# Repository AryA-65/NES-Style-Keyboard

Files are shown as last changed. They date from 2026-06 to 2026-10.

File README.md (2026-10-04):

# NES-Style-Keyboard
- - - -
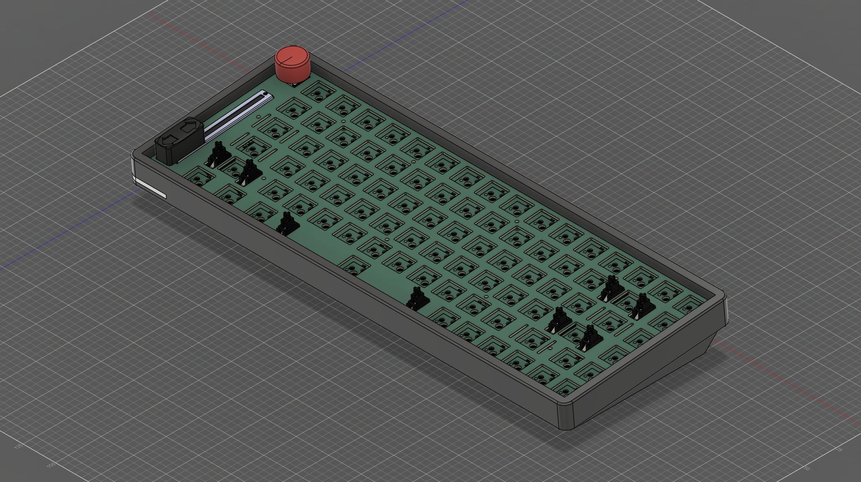
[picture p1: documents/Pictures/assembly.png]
Assembly


## Notice
- - - -
> [!IMPORTANT]  
> It is always advised that you review the files before ordering, as there may be small issues with the current revision.

## Description
- - - -
A friend of mine wanted to buy a keyboard. I convinced him to let me build him one. I decided to build him a custom 75% keyboard, with some extra features based on his preferences, and styled the color scheme to the popular NES. The whole keyboard, including the case, the main PCB, the switch plate and some of the caps, are custom designed by me.

## Gallery

## Features
- - - -
* Sliding Potentiometer
  * One of my friend's requests was to cater the keyboard more towards CAD design. The only right solution, in my opinion, is a sliding potentiometer for zoom control in apps like Fusion. To zoom using the slider, hold CTRL and move the slider up or down. To scroll horizontally, hold SHIFT and move the slider up or down.
* Rotary Encoder
  * The rotary encoder serves as playback control (play/pause/previous/skip), but also as volume control. If volume control is already mapped by the potentiometer, the encoder can serve to switch audio channels controlled by the potentiometer (ex: switching from the music media channel to the system audio channel)
* Addressable RGB LEDs
  * A total of 6 WS2812b leds are included on the left hand side of the keyboard, right next to the sliding potentiometer. They indicate volume level (if controlled by the potentiometer) and/or caps lock.
* Repairable Design
  * The power supplied to the main PCB comes from a small daughterboard at the back, middle of the case. This daughterboard consists of a 3V3 LDO as well as a fuse. The two PCBs are connected through a standard 15cm (0.5ft) USB-C cable, allowing for easy replacement by the user.
* Unibody Body Case
  * The case for the keyboard is as a unibody case. It is built to offer comfort, whilst keeping a thocky sound (it does sound awesome).
* Hot Swappable Keyswitches
  * Does this need to be explain at this point?

## Default keymaps
```
# Base Layer
[_BASE] = LAYOUT(
        KC_ESC, KC_F1, KC_F2, KC_F3, KC_F4, KC_F5, KC_F6, KC_F7, KC_F8, KC_F9, KC_F10, KC_F11, KC_F12, KC_HOME, KC_END, KC_PAUSE,
        KC_GRV, KC_1, KC_2, KC_3, KC_4, KC_5, KC_6, KC_7, KC_8, KC_9, KC_0, KC_MINS, KC_EQL,                    KC_BSPC, KC_INS,
        KC_TAB,     KC_Q, KC_W, KC_E, KC_R, KC_T, KC_Y, KC_U, KC_I, KC_O, KC_P, KC_LBRC, KC_RBRC,               KC_BSLS, KC_DEL,
        KC_CAPS,        KC_A, KC_S, KC_D, KC_F, KC_G, KC_H, KC_J, KC_K, KC_L, KC_SCLN, KC_QUOT,                 KC_ENT, KC_PGUP,
        KC_LSFT,            KC_Z, KC_X, KC_C, KC_V, KC_B, KC_N, KC_M, KC_COMM, KC_DOT, KC_SLSH, KC_RSFT,        KC_UP, KC_PGDN,
        KC_LCTL,    KC_LGUI,    KC_LALT,            KC_SPC,                   KC_RALT, MO(_FL), KC_RCTL, KC_LEFT, KC_DOWN, KC_RIGHT
    )

#Fn Layer
[_FL] = LAYOUT(
        _______, KC_PWR, KC_F2, KC_BRIU, KC_BRID, KC_F5, KC_MSEL, KC_F7, KC_F8, KC_F9, KC_F10, KC_F11, KC_F12, _______, _______, KC_SLEP,
        _______, _______, _______, _______, _______, _______, _______, _______, _______, _______, _______, UG_SPDD, UG_SPDU,              _______, UG_NEXT,
        _______, _______, _______, _______, _______, _______, _______, _______, _______, _______, _______, _______, _______, _______, UG_PREV,
        _______, _______, _______, _______, _______, _______, _______, _______, _______, _______, _______, _______,     _______, UG_SATU,
        _______, _______, _______, _______, _______, _______, _______, _______, _______, _______, _______, _______,     UG_VALU, UG_SATD,
        _______,    _______,    _______,            _______,                    _______, _______, _______, UG_HUED, UG_VALD, UG_HUEU
    )
```

## Parts List
- - - -
|Part|*Price|*Shipping|Link|
|----|---|---|----|
|Keycaps|$34.18|NaN|[XDA Retro NES Keycaps](https://www.aliexpress.com/item/1005007393936770.html?spm=a2g0o.order_list.order_list_main.25.587f1802SPZi3h)|
|Keyswitches (90pcs)|$32.18|NaN|[MMD Cream Switches (45G)](https://www.aliexpress.com/item/1005007083480212.html?spm=a2g0o.order_list.order_list_main.35.587f1802SPZi3h)|
|Hotswap Sockets (110ps)|$12.21|NaN|[110pcs Kailh Hot-swappable Sockets](https://www.aliexpress.com/item/1005007232040760.html?spm=a2g0o.order_list.order_list_main.30.587f1802SPZi3h)|
|Diodes|$3.17|NaN|[100pcs 1N4148W](https://www.aliexpress.com/item/1005009660071572.html?spm=a2g0o.order_list.order_list_main.20.587f1802SPZi3h)|
|Stabilizers|$25.99|NaN|[Durock Screw in Stabilizers V3 (Black)](https://www.aliexpress.com/item/1005003682325989.html?spm=a2g0o.order_list.order_list_main.10.587f1802SPZi3h)|
|USB-C Cable|$12.64|NaN|[6 inch USB C to USB C Cable (3 Pack)](https://www.amazon.ca/dp/B0CLLRBZDB)|
|BOM|$34.96|$8.00|[BOMs](production_files)|
|Main PCB|$31.20|$43.78**|[Main PCB](production_files/gerbers_to_order_main)|
|Daughterboard|$3.00|$43.78**|[Daughterboard PCB](production_files/gerbers_to_order_secondary)|
|Switch Plate****|$0.00|NaN|[Plate PCB](production_files/gerbers_to_order_plate)|
|Case|$65.13|$43.78**|[Enclosure](production_files/3D_files/)|
|Misc.|$6.50***|$43.78**|[Misc. Parts](production_files/3D_files/)|

Total (excluding import fees): $298.66

*All prices are in CAD, check in your own currency before buying.
**Combined shipping for keyboard and daughterboard PCB, misc. items and enclosure.
***Includes encoder knob, slider handle, power led bar and status bar
****I decided to print the switchplate at home, since it was much cheaper per unit and overall compared to ordering it (price will be updated soon).

## Quickstart
- - - -
### 1) First flash
This step if for first flash, right after assembling your PCBs:
1) Download the UF2 prebuilt firmware in [firmware](firmware/).
2) Connect main board to daughterboard through USB-C intercable (**never connect a USB-C cable directly to the main PCB, it will damage the board**).
3) Press and hold EN button on keyboard.
4) Plug USB-C cable from computer to daughterboard, and let go of the EN button.
5) A USB device will appear in your file explorer, drag and drop UF2 file from your downloads folder into the USB device.
6) If the keyboard automatically resets, the flash was successful. Otherwise, try flashing again.

### 2) Reflash
Since the EN button is on the opposite side of the board and not accessible once the keyboard is assembled, I added a key combo that resets the board and enables flashing new firmware:
1) Press and release right CTRL, ESC, left CTRL and END button at the same time.
2) Drag and drop UF2 firmware from your computer onto the keyboard.
3) If the keyboard automatically resets, the flash was successful. Otherwise, try flashing again (step 1).

## Support
- - - -
Coming Soon

## Tools Used
- - - -
- [Kicad](https://www.kicad.org/)
- [Keyboard Layout Editor](https://www.keyboard-layout-editor.com/#/)
- [Autodesk Fusion](https://www.autodesk.com/products/fusion-360/overview)
- [QMK Firmawre](https://qmk.fm/)

## Legal Notice
- - - -
The software and hardware come as is. It is up to the user to review and make sure that they understand the scope of the project before attempting the project.
[GPL V2 License](LICENSE)

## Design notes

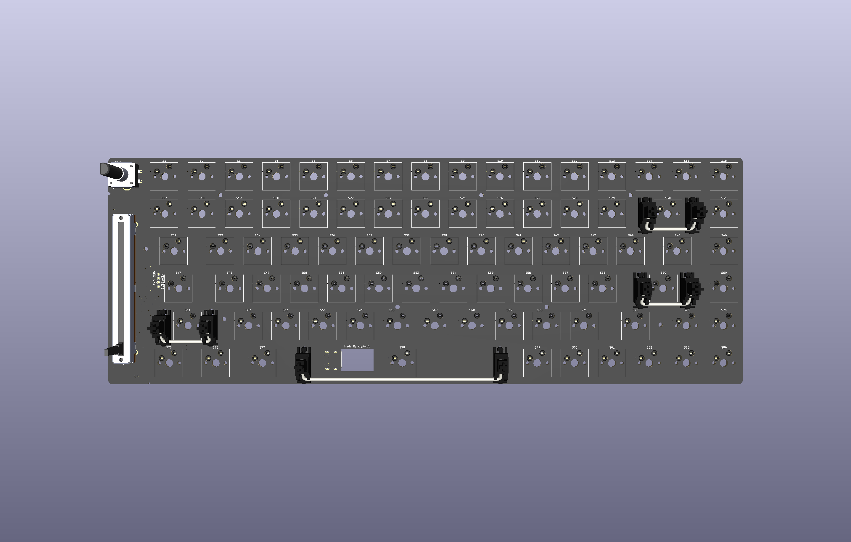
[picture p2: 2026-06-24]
documents/Pictures/main_pcb_picture_f.png

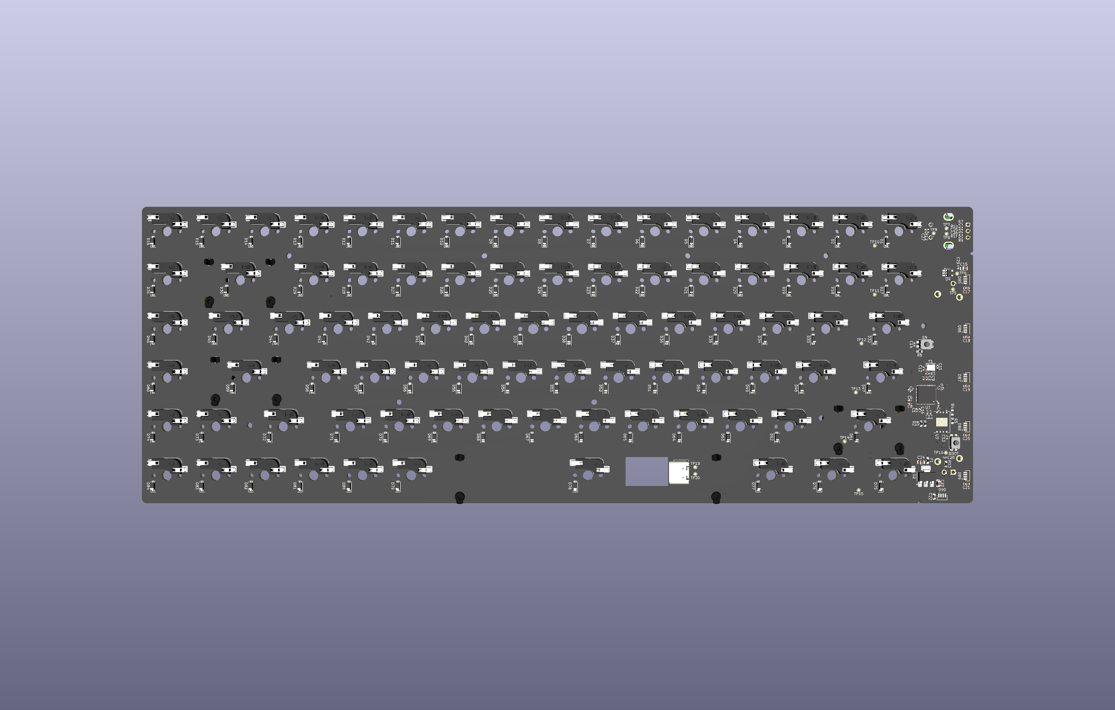
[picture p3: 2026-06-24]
documents/Pictures/main_pcb_picture_b.png

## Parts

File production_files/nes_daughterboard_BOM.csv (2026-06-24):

Reference | Qty | Value | Footprint | Datasheet | Digikey Link | Part Num.
C1,C2 | 2 | 10uF | Capacitor_SMD:C_0805_2012Metric |  | https://www.digikey.ca/en/products/detail/samsung-electro-mechanics/CL21A106KOQNNNE/3886754 | CL21A106KOQNNNE
D1,D2 | 2 | Red | LED_SMD:LED_0603_1608Metric_Pad1.05x0.95mm_HandSolder |  | https://www.digikey.ca/en/products/detail/liteon/LTST-C191KRKT/386837 | LTST-C191KRKT
F1 | 1 | 500mA | Fuse:Fuse_0603_1608Metric |  | https://www.digikey.ca/en/products/detail/panasonic-industry/ERB-RE0R50V/2796788 | ERB-RE0R50V
J1 | 1 | USB_C_Receptacle_USB2.0_16P | Connector_USB:USB_C_Receptacle_GCT_USB4085 | https://www.usb.org/sites/default/files/documents/usb_type-c.zip | https://www.digikey.ca/en/products/detail/gct/USB4085-GF-A/9859662 | USB4085-GF-A
J3 | 1 | USB_C_Receptacle_USB2.0_16P | Connector_USB:USB_C_Receptacle_GCT_USB4105-xx-A_16P_TopMnt_Horizontal | https://www.usb.org/sites/default/files/documents/usb_type-c.zip | https://www.digikey.ca/en/products/detail/gct/USB4105-GF-A/11198441 | USB4105-GF-A
R1,R2 | 2 | 5.11k | Resistor_SMD:R_0603_1608Metric_Pad0.98x0.95mm_HandSolder |  | https://www.digikey.ca/en/products/detail/yageo/RC0603FR-075K1L/727268 | RC0603FR-075K1L
R3 | 1 | 680 | Resistor_SMD:R_0603_1608Metric_Pad0.98x0.95mm_HandSolder |  | https://www.digikey.ca/en/products/detail/yageo/RC0603JR-07680RL/726819 | RC0603JR-07680RL
R4 | 1 | 470 | Resistor_SMD:R_0603_1608Metric_Pad0.98x0.95mm_HandSolder |  | https://www.digikey.ca/en/products/detail/te-connectivity-passive-product/CRGCQ0603F470R/8576286 | CRGCQ0603F470R
U1 | 1 | NCP1117-3.3_SOT223 | Package_TO_SOT_SMD:SOT-223-3_TabPin2 | http://www.onsemi.com/pub_link/Collateral/NCP1117-D.PDF | https://www.digikey.ca/en/products/detail/onsemi/NCP1117LPST33T3G/2194024 | NCP1117LPST33T3G
U2 | 1 | USBLC6-2P6 | Package_TO_SOT_SMD:SOT-666 | https://www.st.com/resource/en/datasheet/usblc6-2.pdf | https://www.digikey.ca/en/products/detail/stmicroelectronics/USBLC6-2P6/1007440 | USBLC6-2P6

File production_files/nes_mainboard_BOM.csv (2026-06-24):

Reference | Qty | Value | Footprint | Part Num. | Digikey Link
C1,C16 | 2 | 1uF | Capacitor_SMD:C_0402_1005Metric | CL05A105KP5NNNC | https://www.digikey.ca/en/products/detail/samsung-electro-mechanics/CL05A105KP5NNNC/3886734
C2,C3,C4,C5,C6,C7,C8,C9,C10,C13,C14,C25,C26,C27,C28,C29 | 16 | 0.1uF | Capacitor_SMD:C_0402_1005Metric | CL05B104KP5NNNC | https://www.digikey.ca/en/products/detail/samsung-electro-mechanics/CL05B104KP5NNNC/3886660
C11,C12 | 2 | 15pF | Capacitor_SMD:C_0402_1005Metric | 885012005026 | https://www.digikey.ca/en/products/detail/w%C3%BCrth-elektronik/885012005026/5453297
C15 | 1 | 10uF | Capacitor_SMD:C_0805_2012Metric | CL21A106KOQNNNE | https://www.digikey.ca/en/products/detail/samsung-electro-mechanics/CL21A106KOQNNNE/3886754
C17,C18,C19,C20,C21,C22 | 6 | 100nF | Capacitor_SMD:C_0603_1608Metric | CL10B104KO8NNNC | https://www.digikey.ca/en/products/detail/samsung-electro-mechanics/CL10B104KO8NNNC/3886663
D1,D2,D3,D4,D5,D6,D7,D8,D9,D10,D11,D12,D13,D14,D15,D16,D17,D18,D19,D20,D21,D22,D23,D24,D25,D26,D27,D28,D29,D30,D31,D32,D33,D34,D35,D36,D37,D38,D39,D40,D41,D42,D43,D44,D45,D46,D47,D48,D49,D50,D51,D52,D53,D54,D55,D56,D57,D58,D59,D60,D61,D62,D63,D64,D65,D66,D67,D68,D69,D70,D71,D72,D73,D74,D75,D76,D77,D78,D79,D80,D81,D82,D83,D84 | 84 | 1N4148W | Diode_SMD:D_SOD-123 | 1N4148W | https://www.digikey.ca/en/products/detail/smc-diode-solutions/1N4148W/6022450
D85,D86,D87,D88,D89,D90 | 6 | WS2812B | LED_WS2812B-4020:LED_WS2812B-4020 |  | https://www.aliexpress.com/item/1005006254176042.html
J1 | 1 | USB_C_Receptacle_USB2.0_16P | Connector_USB:USB_C_Receptacle_GCT_USB4105-xx-A_16P_TopMnt_Horizontal | USB4105-GF-A | https://www.digikey.ca/en/products/detail/gct/USB4105-GF-A/11198441
R1,R2 | 2 | 27.4 | Resistor_SMD:R_0603_1608Metric | RC0603FR-0727R4L | https://www.digikey.ca/en/products/detail/yageo/RC0603FR-0727R4L/727101
R3 | 1 | 1k | Resistor_SMD:R_0402_1005Metric | RC0402FR-071KL | https://www.digikey.ca/en/products/detail/yageo/RC0402FR-071KL/726513
R5 | 1 | 1k | Resistor_SMD:R_0603_1608Metric | RC0603FR-071KL | https://www.digikey.ca/en/products/detail/yageo/RC0603FR-071KL/726843
R7,R9,R10,R11,R12 | 5 | 10k | Resistor_SMD:R_0402_1005Metric | RMCF0402FT10K0 | https://www.digikey.ca/en/products/detail/stackpole-electronics-inc/RMCF0402FT10K0/1761433
R8 | 1 | 10k | Resistor_SMD:R_0603_1608Metric | RMCF0603FT10K0 | https://www.digikey.ca/en/products/detail/stackpole-electronics-inc/RMCF0603FT10K0/1761235
R13 | 1 | 100 | Resistor_SMD:R_0603_1608Metric | RC0603FR-07100RL | https://www.digikey.ca/en/products/detail/yageo/RC0603FR-07100RL/726888
RV1 | 1 | R_Potentiometer | PTA6043_2015DPB103:TRIM_PTA6043-2015DPB103 | PTA6043-2010CIB103 | https://www.digikey.ca/en/products/detail/bourns-inc/PTA6043-2010CIB103/3781224
S1,S2,S3,S4,S5,S6,S7,S8,S9,S10,S11,S12,S13,S14,S15,S16,S17,S18,S19,S20,S21,S22,S23,S24,S25,S26,S27,S28,S29,S31,S33,S34,S35,S36,S37,S38,S39,S40,S41,S42,S43,S44,S46,S48,S49,S50,S51,S52,S53,S54,S55,S56,S57,S58,S60,S62,S63,S64,S65,S66,S67,S68,S69,S70,S71,S73,S74,S79,S80,S81,S82,S83,S84 | 73 | Keyswitch | ScottoKeebs_Hotswap:Hotswap_MX_1.00u
S30 | 1 | Keyswitch | ScottoKeebs_Hotswap:Hotswap_MX_2.00u
S32,S45 | 2 | Keyswitch | ScottoKeebs_Hotswap:Hotswap_MX_1.50u
S47,S72 | 2 | Keyswitch | ScottoKeebs_Hotswap:Hotswap_MX_1.75u
S59,S61 | 2 | Keyswitch | ScottoKeebs_Hotswap:Hotswap_MX_2.25u
S75,S76,S77 | 3 | Keyswitch | ScottoKeebs_Hotswap:Hotswap_MX_1.25u
S78 | 1 | Keyswitch | ScottoKeebs_Hotswap:Hotswap_MX_6.25u
S85,S86,S87 | 3 | Keyswitch | PCM_Mounting_Keyboard_Stabilizer:Stabilizer_Cherry_MX_2.00u
S88 | 1 | Keyswitch | PCM_Mounting_Keyboard_Stabilizer:Stabilizer_Cherry_MX_6.25u
SW1,SW2 | 2 | SW_Push | Button_Switch_SMD:SW_SPST_EVQP2_MiddlePushTravel_H2.5mm | EVQ-P2402W | https://www.digikey.ca/en/products/detail/panasonic-industry/EVQ-P2402W/304152
SW3 | 1 | RotaryEncoder_Switch_MP | Rotary_Encoder:RotaryEncoder_Bourns_Vertical_PEC12R-3x17F-Sxxxx | PEC12R-4217F-S0024 | https://www.digikey.ca/en/products/detail/bourns-inc/PEC12R-4217F-S0024/4499654
TP1,TP2,TP3,TP4,TP5,TP6,TP7,TP8,TP9,TP10,TP11,TP12,TP13,TP14,TP15,TP16,TP19,TP20 | 18 | TestPoint | TestPoint:TestPoint_Pad_D1.0mm
U1 | 1 | RP2040 | Package_DFN_QFN:QFN-56-1EP_7x7mm_P0.4mm_EP3.2x3.2mm_ThermalVias | SC0914(13) | https://www.digikey.ca/en/products/detail/raspberry-pi/SC0914-13/14306010
U3 | 1 | W25Q128JVE | Package_SON:WSON-8-1EP_8x6mm_P1.27mm_EP3.4x4.3mm | W25Q128JVEIQ | https://www.digikey.ca/en/products/detail/winbond-electronics/W25Q128JVEIQ/6819667
U4 | 1 | 74AHCT1G125 | Package_TO_SOT_SMD:SOT-23-5_HandSoldering | SN74AHCT1G125DBVR | https://www.digikey.ca/en/products/detail/texas-instruments/SN74AHCT1G125DBVR/376028
Y1 | 1 | Crystal_GND24 | Crystal:Crystal_SMD_3225-4Pin_3.2x2.5mm | ABM8-272-T3 | https://www.digikey.ca/en/products/detail/abracon-llc/ABM8-272-T3/22472366

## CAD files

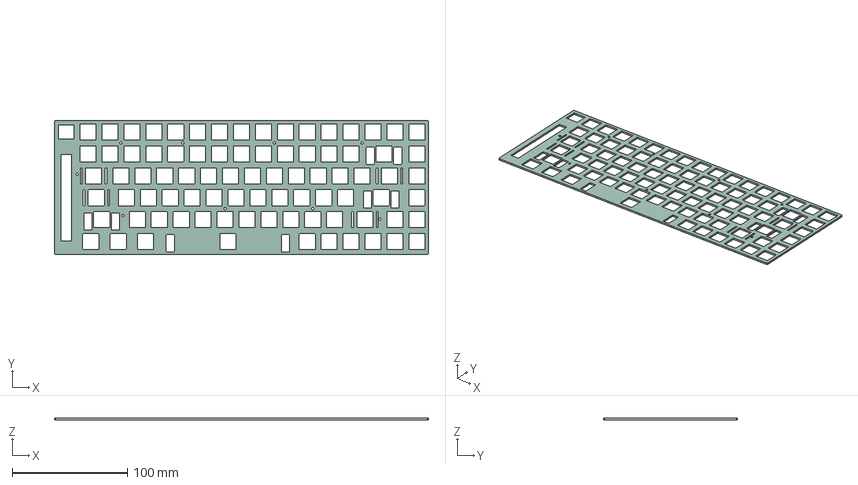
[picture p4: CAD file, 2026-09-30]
nes_switchplate/nes_switchplate.step
325.0 x 116.5 x 1.64 mm
nes_switchplate-unsaved-export-xho6La_silkscreen
nes_switchplate-unsaved-export-xho6La_soldermask x 2
nes_switchplate-unsaved-export-xho6La_PCB

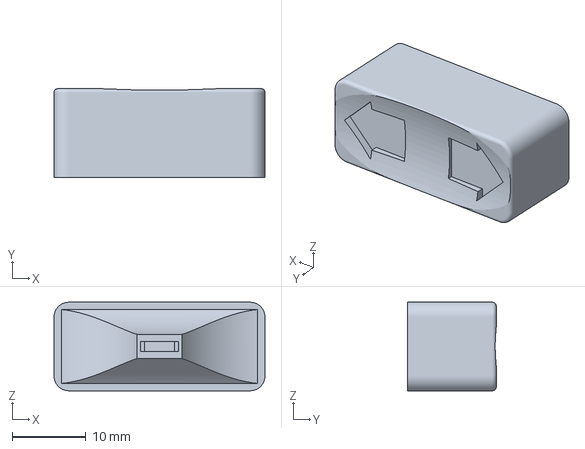
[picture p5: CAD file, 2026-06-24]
production_files/3D_files/Slider Handle.3mf
28.6 x 12.0 x 12.0 mm

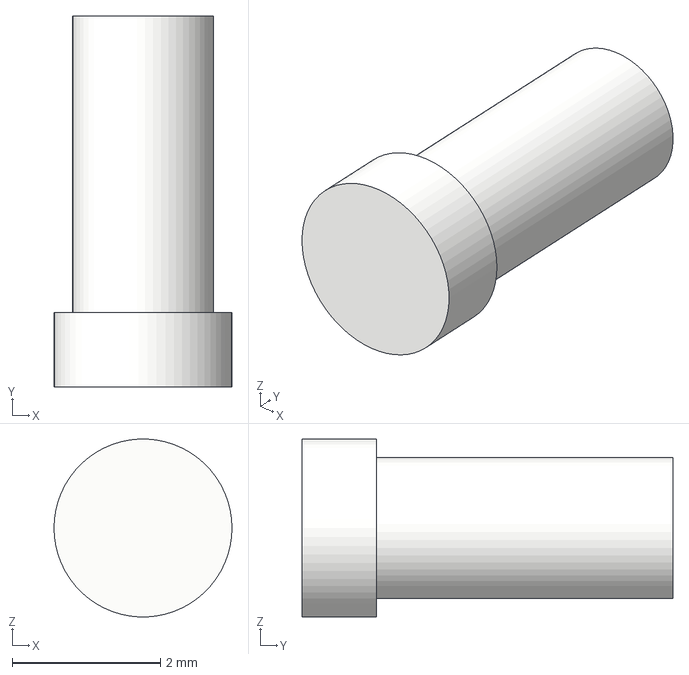
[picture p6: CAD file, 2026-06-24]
production_files/3D_files/pin.3mf
2.40 x 5.00 x 2.40 mm

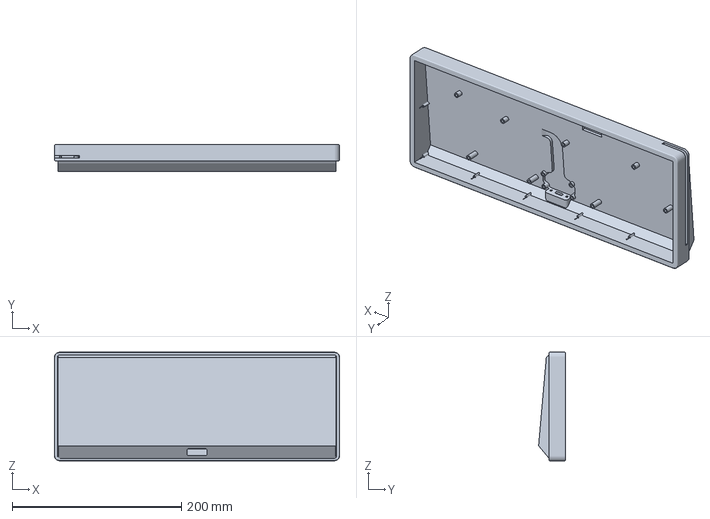
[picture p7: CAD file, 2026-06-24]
production_files/3D_files/Case (V2).3mf
337.0 x 31.8 x 128.5 mm

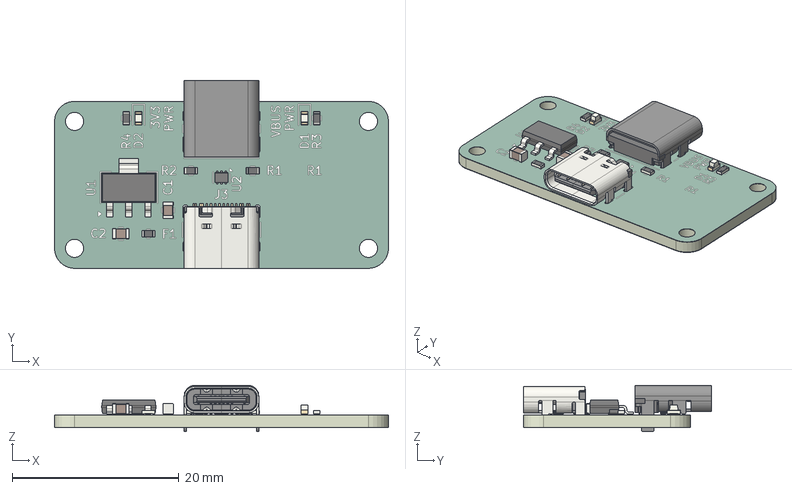
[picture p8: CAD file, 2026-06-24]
production_files/3D_files/daughterboard.step
40.0 x 22.5 x 5.56 mm
R_0603_1608Metric x 4
C_0805_2012Metric x 2
SOT_666
LED_0603_1608Metric x 2
USB_C_Receptacle_GCT_USB4085
USB_C_Receptacle_16P_TopMnt_Horizontal_GCT_USB4105-xx-A
SOT-223
Fuse_0603_1608Metric
nes_keyboard_daughterboard_silkscreen
nes_keyboard_daughterboard_soldermask x 2
nes_keyboard_daughterboard_PCB

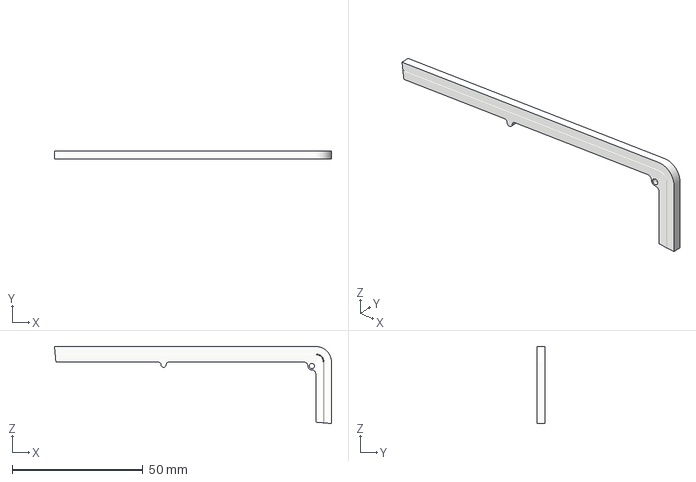
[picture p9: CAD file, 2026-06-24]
production_files/3D_files/Status Bar (V2).3mf
106.0 x 3.05 x 29.5 mm

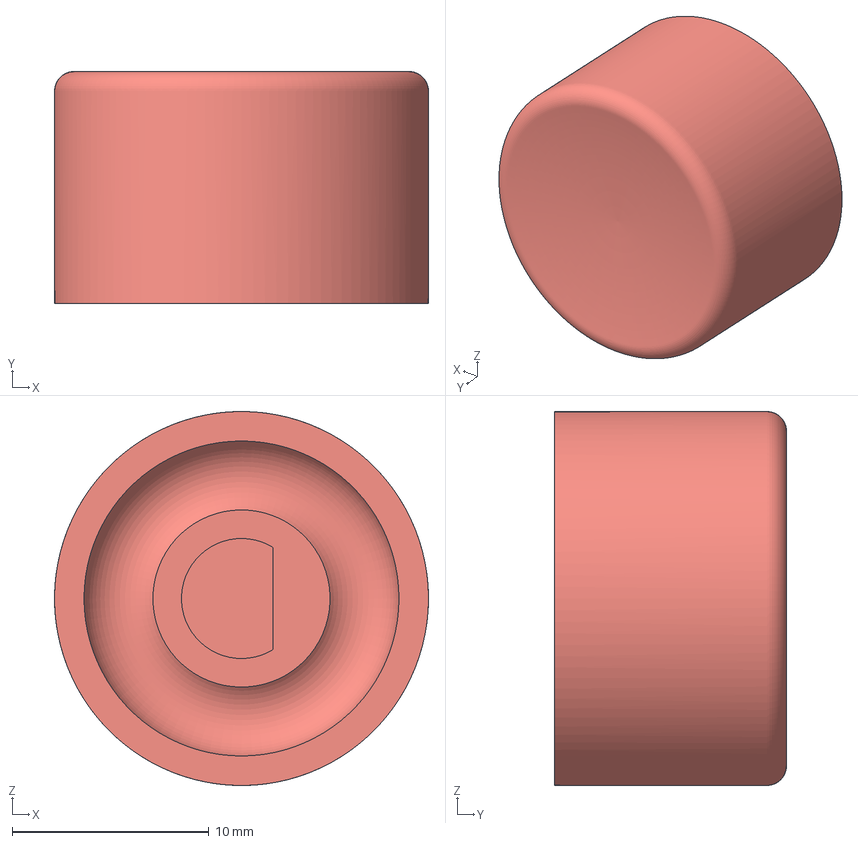
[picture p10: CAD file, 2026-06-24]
production_files/3D_files/Knob.3mf
19.0 x 11.8 x 19.0 mm

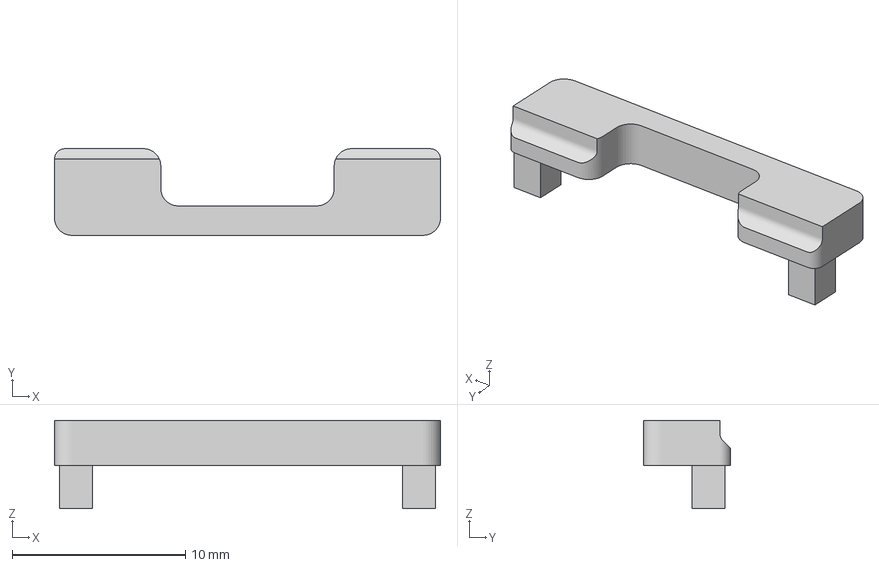
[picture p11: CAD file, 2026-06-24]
production_files/3D_files/PWR Status (V2).3mf
22.3 x 5.00 x 5.10 mm

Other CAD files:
production_files/3D_files/switchplate.step

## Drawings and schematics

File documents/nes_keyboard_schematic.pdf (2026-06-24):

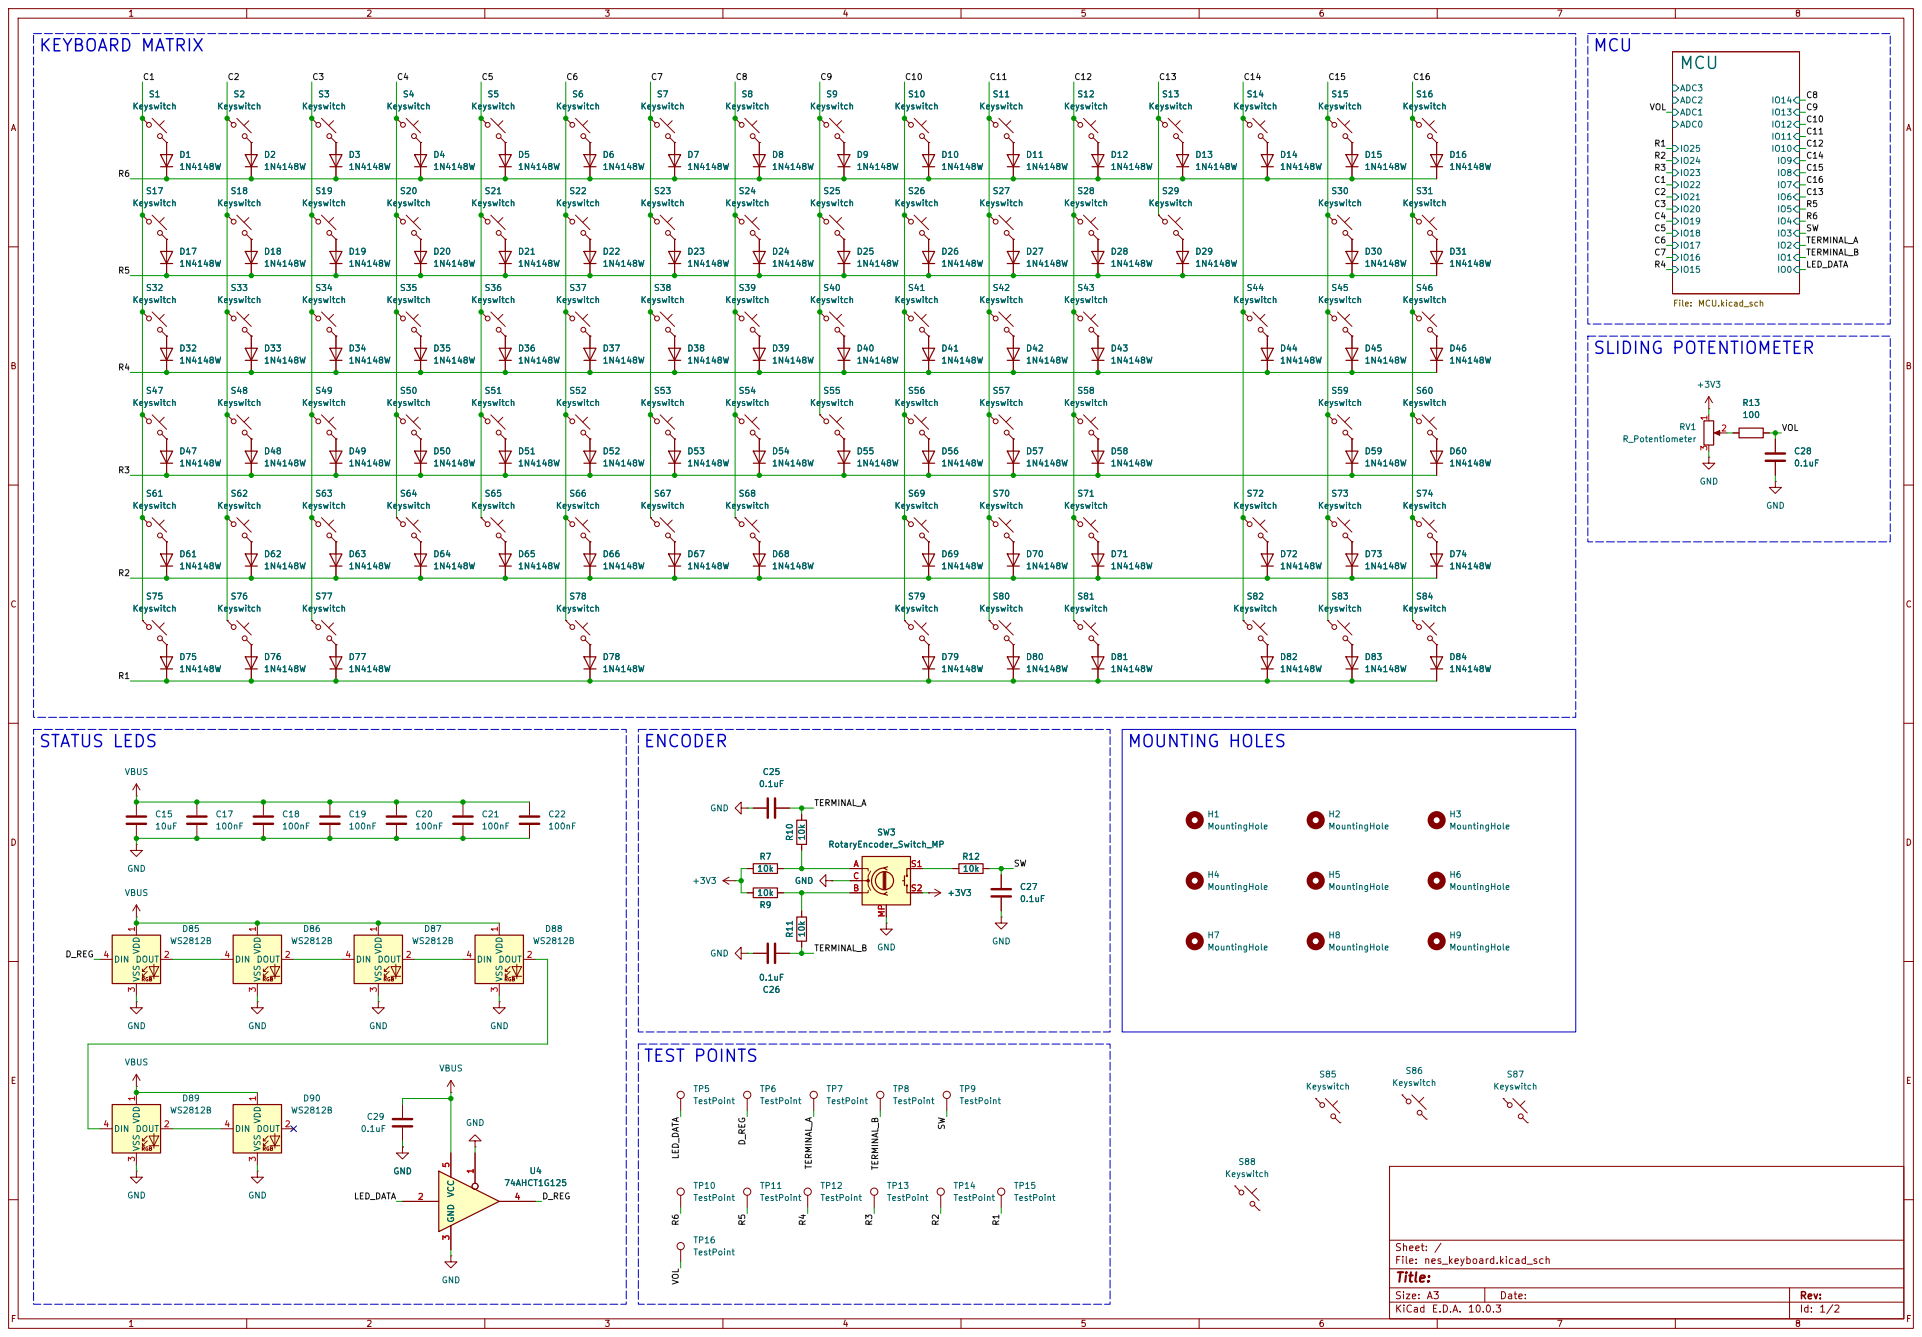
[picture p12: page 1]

S28 Keyswitch S43 Keyswitch S42 Keyswitch S27 Keyswitch D27

Size: A3 | Rev: | F Date:
KiCad E.D.A. 10.0.3 | Id: 1/2

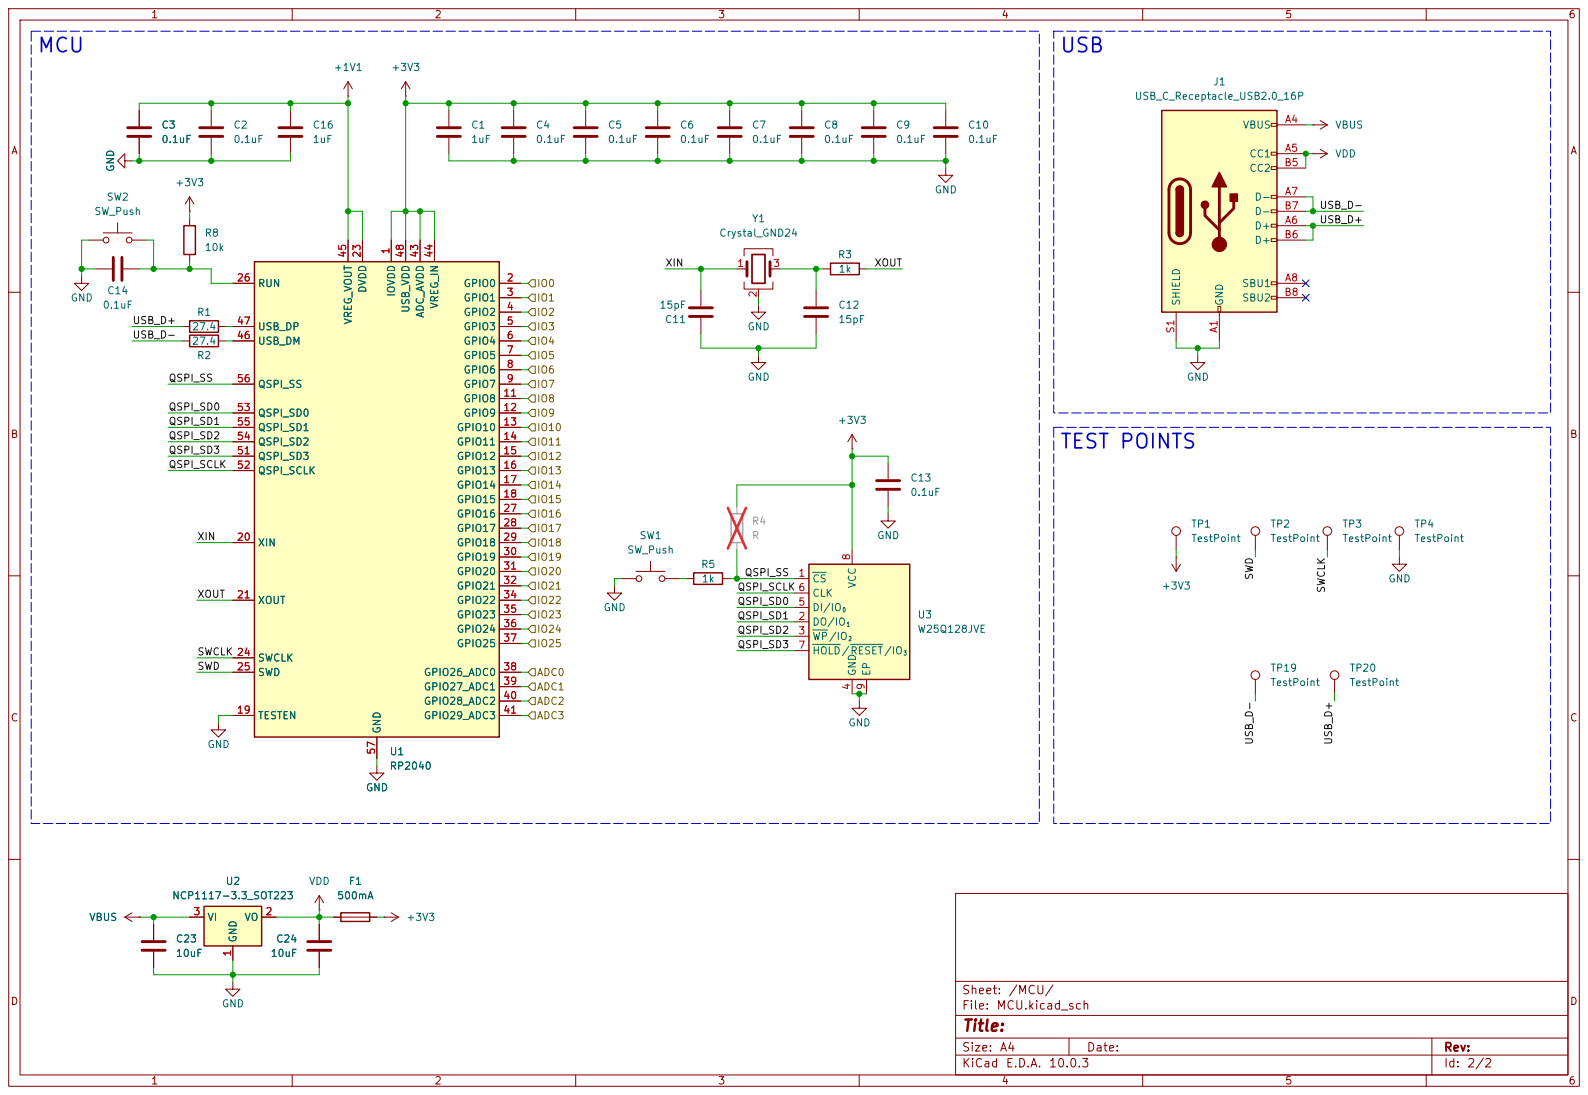
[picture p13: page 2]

4 DI/IO0 5 CLK 6 HOLD/RESET/IO3 7 VCC

Size: A4 | Rev:
KiCad E.D.A. 10.0.3 | Id: 2/2

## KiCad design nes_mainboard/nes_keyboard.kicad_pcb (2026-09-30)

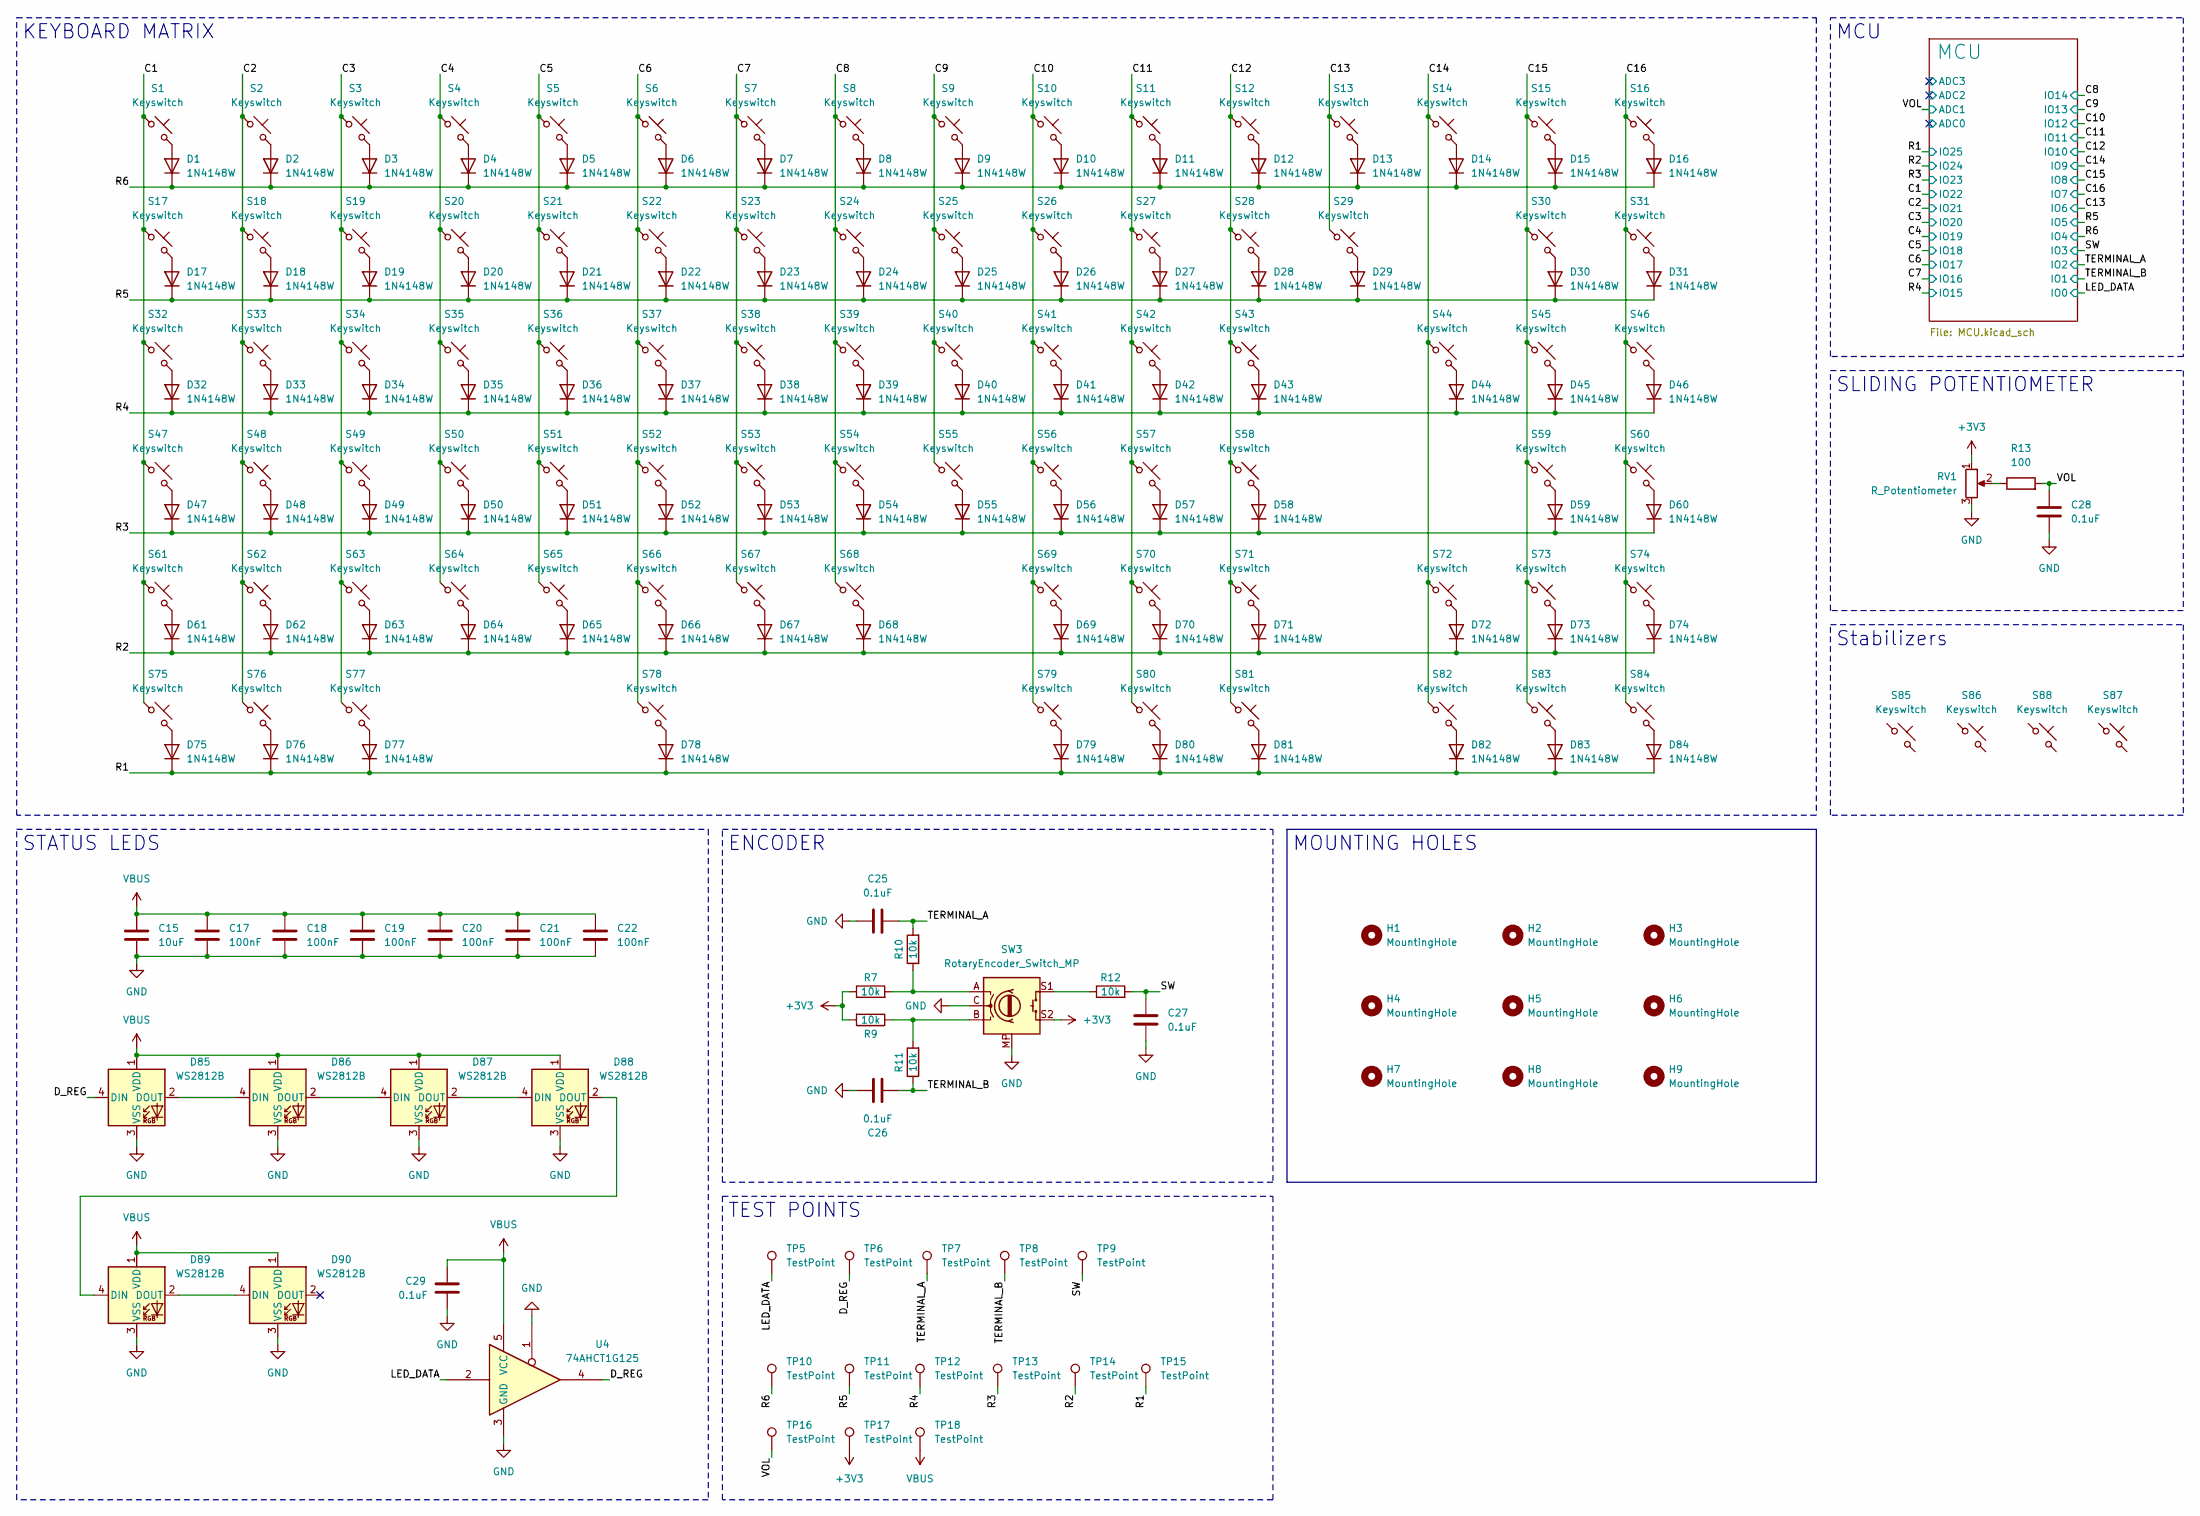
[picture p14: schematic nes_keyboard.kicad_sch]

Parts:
C15: 10uF; C_0805_2012Metric; Part Num. CL21A106KOQNNNE
C17, C18, C19, C20, C21, C22: 100nF; C_0603_1608Metric; Part Num. CL10B104KO8NNNC
C25, C26, C27, C28, C29: 0.1uF; C_0402_1005Metric; Part Num. CL05B104KP5NNNC
D1, D2, D3, D4, D5, D6, D7, D8, D9, D10, D11, D12, D13, D14, D15, D16, D17, D18, D19, D20, D21, D22, D23, D24, D25, D26, D27, D28, D29, D30, D31, D32, D33, D34, D35, D36, D37, D38, D39, D40, D41, D42, D43, D44, D45, D46, D47, D48, D49, D50, D51, D52, D53, D54, D55, D56, D57, D58, D59, D60, D61, D62, D63, D64, D65, D66, D67, D68, D69, D70, D71, D72, D73, D74, D75, D76, D77, D78, D79, D80, D81, D82, D83, D84: 1N4148W; D_SOD-123; Part Num. 1N4148W
D85, D86, D87, D88, D89, D90: WS2812B; LED_WS2812B-4020
H1, H2, H3, H4, H5, H6, H7, H8, H9: MountingHole; MountingHole_2.2mm_M2_Pad
R7, R9, R10, R11, R12: 10k; R_0402_1005Metric; Part Num. RMCF0402FT10K0
R13: 100; R_0603_1608Metric; Part Num. RC0603FR-07100RL
RV1: R_Potentiometer; TRIM_PTA6043-2015DPB103; Part Num. PTA6043-2010CIB103
S1, S2, S3, S4, S5, S6, S7, S8, S9, S10, S11, S12, S13, S14, S15, S16, S17, S18, S19, S20, S21, S22, S23, S24, S25, S26, S27, S28, S29, S31, S33, S34, S35, S36, S37, S38, S39, S40, S41, S42, S43, S44, S46, S48, S49, S50, S51, S52, S53, S54, S55, S56, S57, S58, S60, S62, S63, S64, S65, S66, S67, S68, S69, S70, S71, S73, S74, S79, S80, S81, S82, S83, S84: Keyswitch; Hotswap_MX_1.00u
S30: Keyswitch; Hotswap_MX_2.00u
S32, S45: Keyswitch; Hotswap_MX_1.50u
S47, S72: Keyswitch; Hotswap_MX_1.75u
S59, S61: Keyswitch; Hotswap_MX_2.25u
S75, S76, S77: Keyswitch; Hotswap_MX_1.25u
S78: Keyswitch; Hotswap_MX_6.25u
S85, S86, S87: Keyswitch; Stabilizer_Cherry_MX_2.00u
S88: Keyswitch; Stabilizer_Cherry_MX_6.25u
SW3: RotaryEncoder_Switch_MP; RotaryEncoder_Bourns_Vertical_PEC12R-3x17F-Sxxxx; Part Num. PEC12R-4217F-S0024
TP5, TP6, TP7, TP8, TP9, TP10, TP11, TP12, TP13, TP14, TP15, TP16, TP17, TP18: TestPoint; TestPoint_Pad_D1.0mm
U4: 74AHCT1G125; SOT-23-5_HandSoldering; Part Num. SN74AHCT1G125DBVR

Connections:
+3V3: R7.1, R9.2, RV1.1, SW3.S2, TP17.1 (1_1); also elsewhere on the board
/C1: S1.1, S17.1, S32.1, S47.1, S61.1, S75.1; also elsewhere on the board
/C2: S2.1, S18.1, S33.1, S48.1, S62.1, S76.1; also elsewhere on the board
/C3: S3.1, S19.1, S34.1, S49.1, S63.1, S77.1; also elsewhere on the board
/C4: S4.1, S20.1, S35.1, S50.1, S64.1; also elsewhere on the board
/C5: S5.1, S21.1, S36.1, S51.1, S65.1; also elsewhere on the board
/C6: S6.1, S22.1, S37.1, S52.1, S66.1, S78.1; also elsewhere on the board
/C7: S7.1, S23.1, S38.1, S53.1, S67.1; also elsewhere on the board
/C8: S8.1, S24.1, S39.1, S54.1, S68.1; also elsewhere on the board
/C9: S9.1, S25.1, S40.1, S55.1; also elsewhere on the board
/C10: S10.1, S26.1, S41.1, S56.1, S69.1, S79.1; also elsewhere on the board
/C11: S11.1, S27.1, S42.1, S57.1, S70.1, S80.1; also elsewhere on the board
/C12: S12.1, S28.1, S43.1, S58.1, S71.1, S81.1; also elsewhere on the board
/C13: S13.1, S29.1; also elsewhere on the board
/C14: S14.1, S44.1, S72.1, S82.1; also elsewhere on the board
/C15: S15.1, S30.1, S45.1, S59.1, S73.1, S83.1; also elsewhere on the board
/C16: S16.1, S31.1, S46.1, S60.1, S74.1, S84.1; also elsewhere on the board
/D_REG: D85.4 (DIN), TP6.1 (1_1), U4.4
/LED_DATA: TP5.1 (1_1), U4.2; also elsewhere on the board
/R1: D75.1 (K), D76.1 (K), D77.1 (K), D78.1 (K), D79.1 (K), D80.1 (K), D81.1 (K), D82.1 (K), D83.1 (K), D84.1 (K), TP15.1 (1_1); also elsewhere on the board
/R2: D61.1 (K), D62.1 (K), D63.1 (K), D64.1 (K), D65.1 (K), D66.1 (K), D67.1 (K), D68.1 (K), D69.1 (K), D70.1 (K), D71.1 (K), D72.1 (K), D73.1 (K), D74.1 (K), TP14.1 (1_1); also elsewhere on the board
/R3: D47.1 (K), D48.1 (K), D49.1 (K), D50.1 (K), D51.1 (K), D52.1 (K), D53.1 (K), D54.1 (K), D55.1 (K), D56.1 (K), D57.1 (K), D58.1 (K), D59.1 (K), D60.1 (K), TP13.1 (1_1); also elsewhere on the board
/R4: D32.1 (K), D33.1 (K), D34.1 (K), D35.1 (K), D36.1 (K), D37.1 (K), D38.1 (K), D39.1 (K), D40.1 (K), D41.1 (K), D42.1 (K), D43.1 (K), D44.1 (K), D45.1 (K), D46.1 (K), TP12.1 (1_1); also elsewhere on the board
/R5: D17.1 (K), D18.1 (K), D19.1 (K), D20.1 (K), D21.1 (K), D22.1 (K), D23.1 (K), D24.1 (K), D25.1 (K), D26.1 (K), D27.1 (K), D28.1 (K), D29.1 (K), D30.1 (K), D31.1 (K), TP11.1 (1_1); also elsewhere on the board
/R6: D1.1 (K), D2.1 (K), D3.1 (K), D4.1 (K), D5.1 (K), D6.1 (K), D7.1 (K), D8.1 (K), D9.1 (K), D10.1 (K), D11.1 (K), D12.1 (K), D13.1 (K), D14.1 (K), D15.1 (K), D16.1 (K), TP10.1 (1_1); also elsewhere on the board
/SW: C27.1, R12.2, TP9.1 (1_1); also elsewhere on the board
/TERMINAL_A: C25.2, R10.2, TP7.1 (1_1); also elsewhere on the board
/TERMINAL_B: C26.1, R11.1, TP8.1 (1_1); also elsewhere on the board
/VOL: C28.2, R13.2, TP16.1 (1_1); also elsewhere on the board
GND: C15.2, C17.2, C18.2, C19.2, C20.2, C21.2, C22.2, C25.1, C26.2, C27.2, C28.1, C29.2, D85.3 (VSS), D86.3 (VSS), D87.3 (VSS), D88.3 (VSS), D89.3 (VSS), D90.3 (VSS), RV1.3, SW3.C, SW3.MP, U4.1, U4.3 (GND); also elsewhere on the board
unnamed: D1.2 (A), S1.2
unnamed: D2.2 (A), S2.2
unnamed: D3.2 (A), S3.2
unnamed: D4.2 (A), S4.2
unnamed: D5.2 (A), S5.2
unnamed: D6.2 (A), S6.2
unnamed: D7.2 (A), S7.2
unnamed: D8.2 (A), S8.2
unnamed: D9.2 (A), S9.2
unnamed: D10.2 (A), S10.2
unnamed: D11.2 (A), S11.2
unnamed: D12.2 (A), S12.2
unnamed: D13.2 (A), S13.2
unnamed: D14.2 (A), S14.2
unnamed: D15.2 (A), S15.2
unnamed: D16.2 (A), S16.2
unnamed: D17.2 (A), S17.2
unnamed: D18.2 (A), S18.2
unnamed: D19.2 (A), S19.2
unnamed: D20.2 (A), S20.2
unnamed: D21.2 (A), S21.2
unnamed: D22.2 (A), S22.2
unnamed: D23.2 (A), S23.2
unnamed: D24.2 (A), S24.2
unnamed: D25.2 (A), S25.2
unnamed: D26.2 (A), S26.2
unnamed: D27.2 (A), S27.2
unnamed: D28.2 (A), S28.2
unnamed: D29.2 (A), S29.2
unnamed: D30.2 (A), S30.2
unnamed: D31.2 (A), S31.2
unnamed: D32.2 (A), S32.2
unnamed: D33.2 (A), S33.2
unnamed: D34.2 (A), S34.2
unnamed: D35.2 (A), S35.2
unnamed: D36.2 (A), S36.2
unnamed: D37.2 (A), S37.2
unnamed: D38.2 (A), S38.2
unnamed: D39.2 (A), S39.2
unnamed: D40.2 (A), S40.2
unnamed: D41.2 (A), S41.2
unnamed: D42.2 (A), S42.2
unnamed: D43.2 (A), S43.2
unnamed: D44.2 (A), S44.2
unnamed: D45.2 (A), S45.2
unnamed: D46.2 (A), S46.2
unnamed: D47.2 (A), S47.2
unnamed: D48.2 (A), S48.2
unnamed: D49.2 (A), S49.2
unnamed: D50.2 (A), S50.2
unnamed: D51.2 (A), S51.2
unnamed: D52.2 (A), S52.2
unnamed: D53.2 (A), S53.2
unnamed: D54.2 (A), S54.2
unnamed: D55.2 (A), S55.2
unnamed: D56.2 (A), S56.2
unnamed: D57.2 (A), S57.2
unnamed: D58.2 (A), S58.2
unnamed: D59.2 (A), S59.2
unnamed: D60.2 (A), S60.2
unnamed: D61.2 (A), S61.2
unnamed: D62.2 (A), S62.2
unnamed: D63.2 (A), S63.2
unnamed: D64.2 (A), S64.2
unnamed: D65.2 (A), S65.2
unnamed: D66.2 (A), S66.2
unnamed: D67.2 (A), S67.2
unnamed: D68.2 (A), S68.2
unnamed: D69.2 (A), S69.2
unnamed: D70.2 (A), S70.2
unnamed: D71.2 (A), S71.2
unnamed: D72.2 (A), S72.2
unnamed: D73.2 (A), S73.2
unnamed: D74.2 (A), S74.2
unnamed: D75.2 (A), S75.2
unnamed: D76.2 (A), S76.2
unnamed: D77.2 (A), S77.2
unnamed: D78.2 (A), S78.2
unnamed: D79.2 (A), S79.2
unnamed: D80.2 (A), S80.2
unnamed: D81.2 (A), S81.2
unnamed: D82.2 (A), S82.2
unnamed: D83.2 (A), S83.2
unnamed: D84.2 (A), S84.2
unnamed: D85.2 (DOUT), D86.4 (DIN)
unnamed: D86.2 (DOUT), D87.4 (DIN)
unnamed: D87.2 (DOUT), D88.4 (DIN)
unnamed: D88.2 (DOUT), D89.4 (DIN)
unnamed: D89.2 (DOUT), D90.4 (DIN)
unnamed: R7.2, R10.1, SW3.A
unnamed: R9.1, R11.2, SW3.B
unnamed: R12.1, SW3.S1
unnamed: R13.1, RV1.2
VBUS: C15.1, C17.1, C18.1, C19.1, C20.1, C21.1, C22.1, C29.1, D85.1 (VDD), D86.1 (VDD), D87.1 (VDD), D88.1 (VDD), D89.1 (VDD), D90.1 (VDD), TP18.1 (1_1), U4.5 (VCC); also elsewhere on the board

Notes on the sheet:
KEYBOARD MATRIX
MOUNTING HOLES
TEST POINTS
ENCODER
MCU
STATUS LEDS
Stabilizers
SLIDING POTENTIOMETER

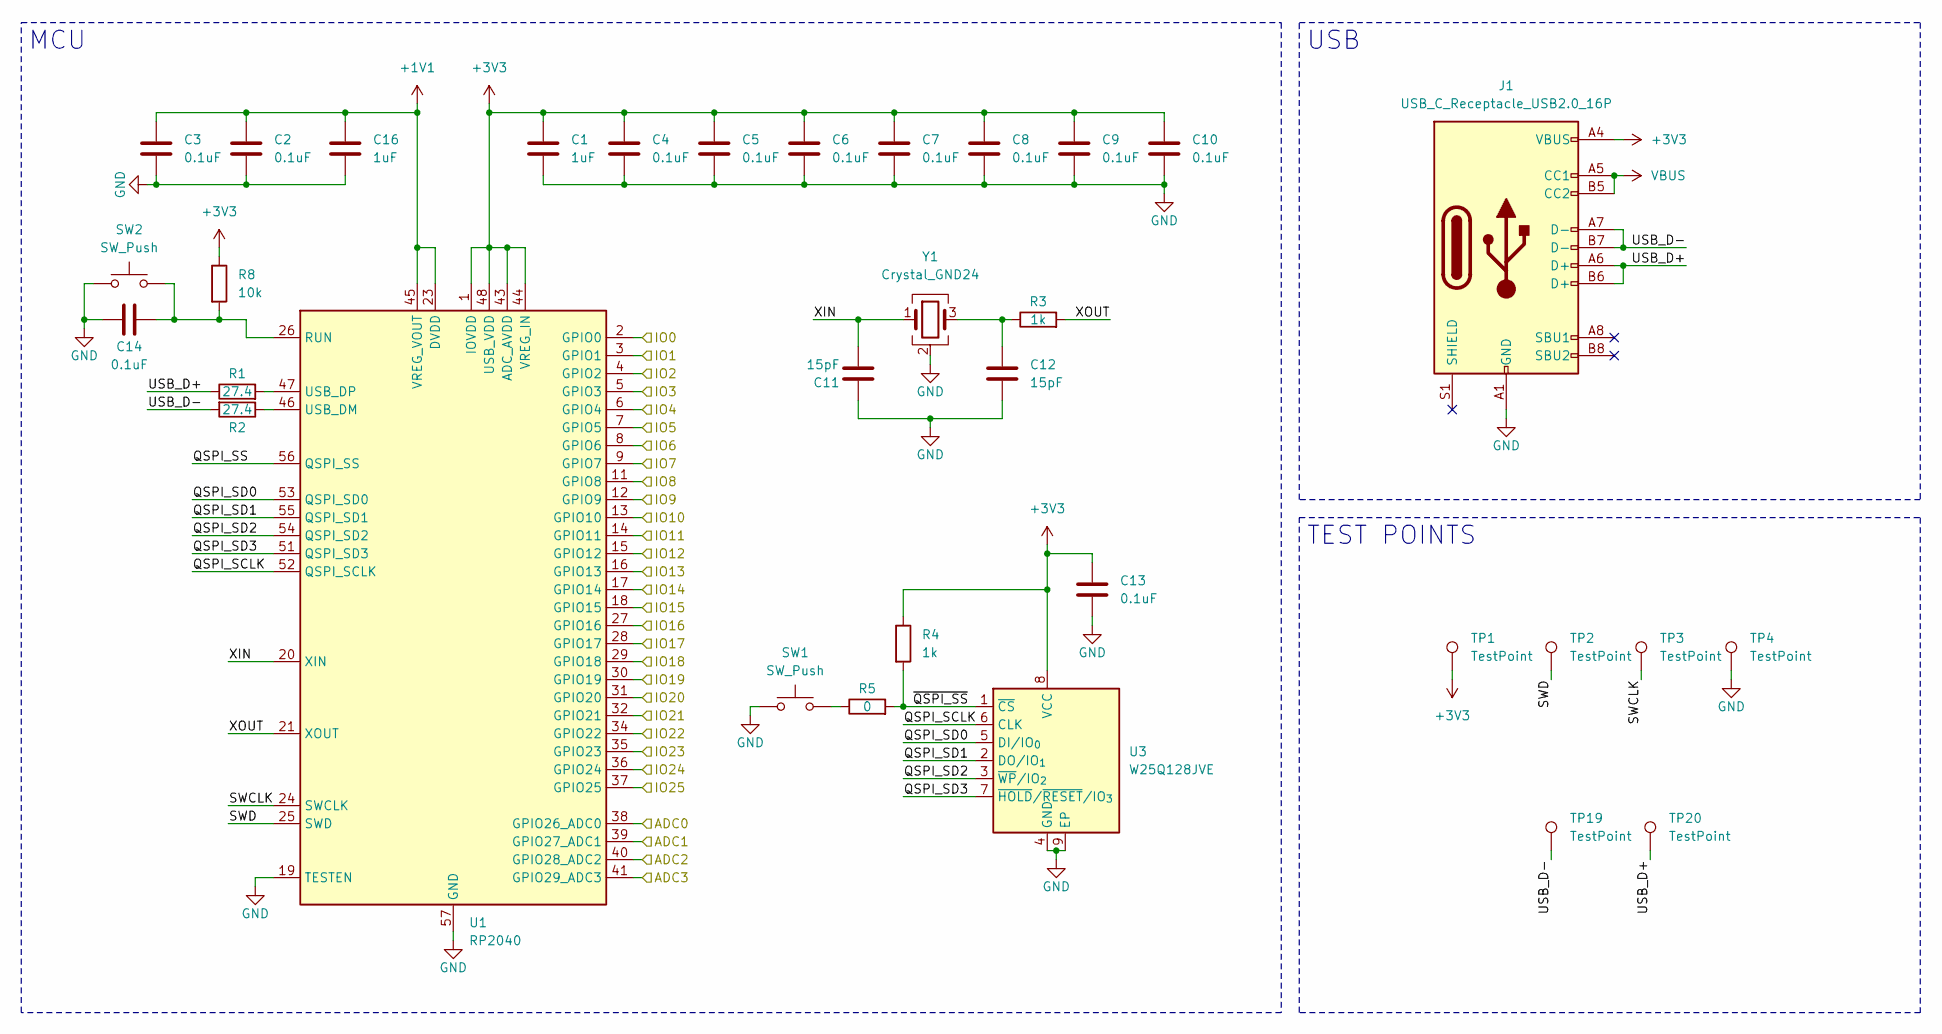
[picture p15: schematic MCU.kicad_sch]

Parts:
C1, C16: 1uF; C_0402_1005Metric; Part Num. CL05A105KP5NNNC
C2, C3, C4, C5, C6, C7, C8, C9, C10, C13, C14: 0.1uF; C_0402_1005Metric; Part Num. CL05B104KP5NNNC
C11, C12: 15pF; C_0402_1005Metric; Part Num. 885012005026
J1: USB_C_Receptacle_USB2.0_16P; USB_C_Receptacle_GCT_USB4105-xx-A_16P_TopMnt_Horizontal; Part Num. USB4105-GF-A
R1, R2: 27.4; R_0603_1608Metric; Part Num. RC0603FR-0727R4L
R3: 1k; R_0402_1005Metric; Part Num. RC0402FR-071KL
R4: 1k; R_0603_1608Metric; Part Num. RC0603FR-071KL
R5: 0; R_0603_1608Metric
R8: 10k; R_0603_1608Metric; Part Num. RMCF0603FT10K0
SW1, SW2: SW_Push; SW_SPST_EVQP2_MiddlePushTravel_H2.5mm; Part Num. EVQ-P2402W
TP1, TP2, TP3, TP4, TP19, TP20: TestPoint; TestPoint_Pad_D1.0mm
U1: RP2040; QFN-56-1EP_7x7mm_P0.4mm_EP3.2x3.2mm; Part Num. SC0914(13)
U3: W25Q128JVE; WSON-8-1EP_8x6mm_P1.27mm_EP3.4x4.3mm; Part Num. W25Q128JVEIQ
Y1: Crystal_GND24; Crystal_SMD_3225-4Pin_3.2x2.5mm; Part Num. ABM8-272-T3

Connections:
+1V1: C2.1, C3.1, C16.1, U1.23 (DVDD), U1.45 (VREG_VOUT), U1.50 (DVDD)
+3V3: C1.1, C4.1, C5.1, C6.1, C7.1, C8.1, C9.1, C10.1, C13.1, J1.A4 (VBUS), J1.A9 (VBUS), J1.B4 (VBUS), J1.B9 (VBUS), R4.1, R8.1, TP1.1 (1_1), U1.1 (IOVDD), U1.10 (IOVDD), U1.22 (IOVDD), U1.33 (IOVDD), U1.42 (IOVDD), U1.43 (ADC_AVDD), U1.44 (VREG_IN), U1.48 (USB_VDD), U1.49 (IOVDD), U3.8 (VCC); also elsewhere on the board
/C1: U1.34 (GPIO22); also elsewhere on the board
/C2: U1.32 (GPIO21); also elsewhere on the board
/C3: U1.31 (GPIO20); also elsewhere on the board
/C4: U1.30 (GPIO19); also elsewhere on the board
/C5: U1.29 (GPIO18); also elsewhere on the board
/C6: U1.28 (GPIO17); also elsewhere on the board
/C7: U1.27 (GPIO16); also elsewhere on the board
/C8: U1.17 (GPIO14); also elsewhere on the board
/C9: U1.16 (GPIO13); also elsewhere on the board
/C10: U1.15 (GPIO12); also elsewhere on the board
/C11: U1.14 (GPIO11); also elsewhere on the board
/C12: U1.13 (GPIO10); also elsewhere on the board
/C13: U1.8 (GPIO6); also elsewhere on the board
/C14: U1.12 (GPIO9); also elsewhere on the board
/C15: U1.11 (GPIO8); also elsewhere on the board
/C16: U1.9 (GPIO7); also elsewhere on the board
/LED_DATA: U1.2 (GPIO0); also elsewhere on the board
/MCU/ADC0: U1.38 (GPIO26_ADC0)
/MCU/ADC2: U1.40 (GPIO28_ADC2)
/MCU/ADC3: U1.41 (GPIO29_ADC3)
/MCU/QSPI_SCLK: U1.52 (QSPI_SCLK), U3.6 (CLK)
/MCU/QSPI_SD0: U1.53 (QSPI_SD0), U3.5 (DI/IO_{0})
/MCU/QSPI_SD1: U1.55 (QSPI_SD1), U3.2 (DO/IO_{1})
/MCU/QSPI_SD2: U1.54 (QSPI_SD2), U3.3 (~WP/IO_{2})
/MCU/QSPI_SD3: U1.51 (QSPI_SD3), U3.7 (~HOLD/~RESET/IO_{3})
/MCU/QSPI_SS: U1.56 (QSPI_SS)
/MCU/SWCLK: TP3.1 (1_1), U1.24 (SWCLK)
/MCU/SWD: TP2.1 (1_1), U1.25 (SWD)
/MCU/USB_D+: J1.A6 (D+), J1.B6 (D+), R1.1, TP20.1 (1_1)
/MCU/USB_D-: J1.A7 (D-), J1.B7 (D-), R2.2, TP19.1 (1_1)
/MCU/XIN: C11.2, U1.20 (XIN), Y1.1
/MCU/XOUT: R3.2, U1.21 (XOUT)
/MCU/~QSPI_SS: R4.2, R5.2, U3.1 (~CS)
/R1: U1.37 (GPIO25); also elsewhere on the board
/R2: U1.36 (GPIO24); also elsewhere on the board
/R3: U1.35 (GPIO23); also elsewhere on the board
/R4: U1.18 (GPIO15); also elsewhere on the board
/R5: U1.7 (GPIO5); also elsewhere on the board
/R6: U1.6 (GPIO4); also elsewhere on the board
/SW: U1.5 (GPIO3); also elsewhere on the board
/TERMINAL_A: U1.4 (GPIO2); also elsewhere on the board
/TERMINAL_B: U1.3 (GPIO1); also elsewhere on the board
/VOL: U1.39 (GPIO27_ADC1); also elsewhere on the board
GND: C1.2, C2.2, C3.2, C4.2, C5.2, C6.2, C7.2, C8.2, C9.2, C10.2, C11.1, C12.2, C13.2, C14.1, C16.2, J1.A1 (GND), J1.A12 (GND), J1.B1 (GND), J1.B12 (GND), SW1.1, SW2.1, TP4.1 (1_1), U1.19 (TESTEN), U1.57 (GND), U3.4 (GND), U3.9 (EP), Y1.2 (G), Y1.4 (G); also elsewhere on the board
unnamed: C12.1, R3.1, Y1.3
unnamed: R5.1, SW1.2
unnamed: C14.2, R8.2, SW2.2, U1.26 (RUN)
unnamed: R2.1, U1.46 (USB_DM)
unnamed: R1.2, U1.47 (USB_DP)
VBUS: J1.A5 (CC1), J1.B5 (CC2); also elsewhere on the board

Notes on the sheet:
MCU
USB
TEST POINTS

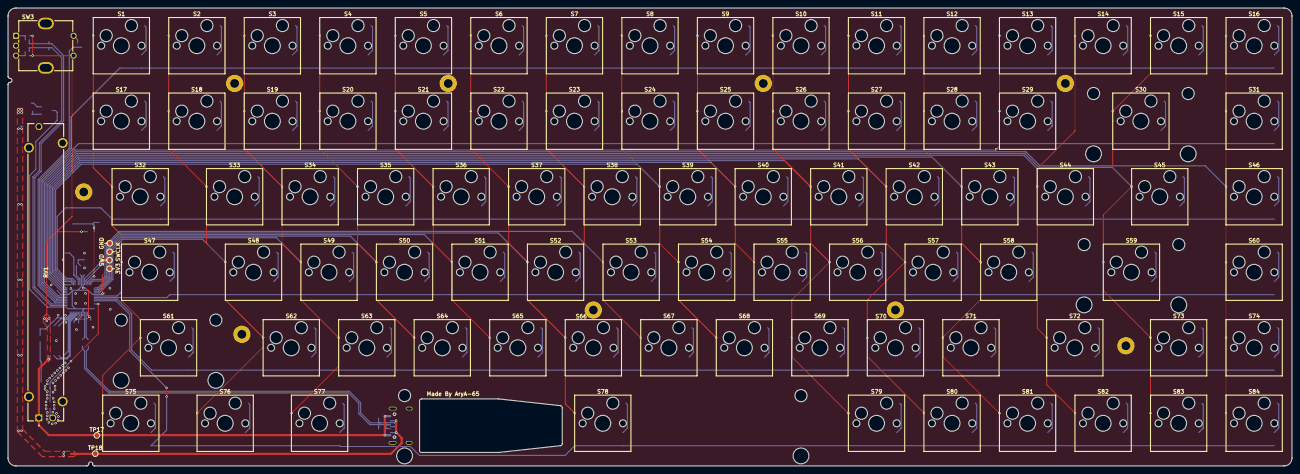
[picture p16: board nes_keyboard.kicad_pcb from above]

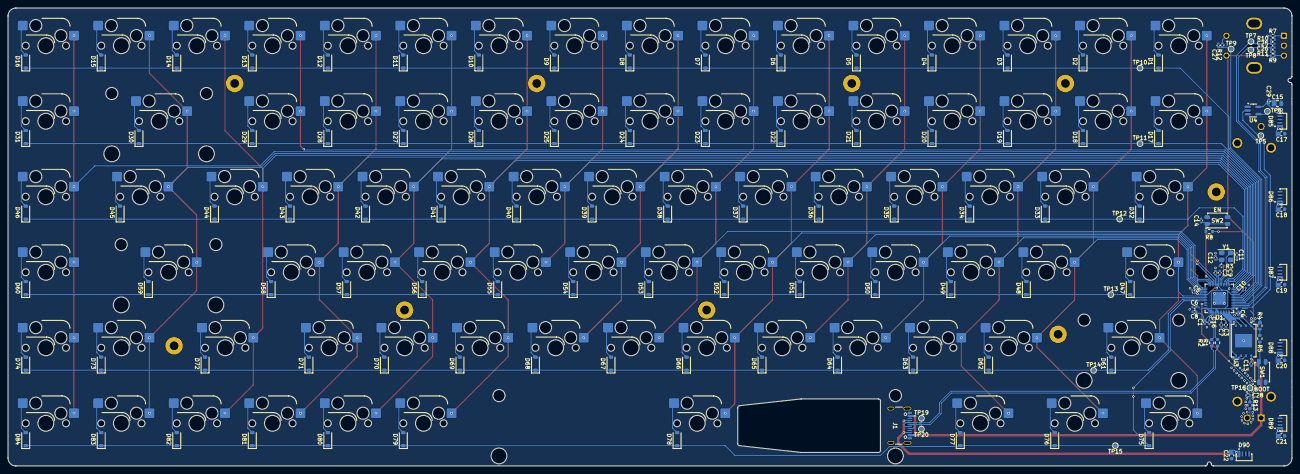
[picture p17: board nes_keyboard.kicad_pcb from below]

Board: 2 copper layers, 323.9 x 115.5 mm, 255 parts (150 on the bottom side), 142 nets.

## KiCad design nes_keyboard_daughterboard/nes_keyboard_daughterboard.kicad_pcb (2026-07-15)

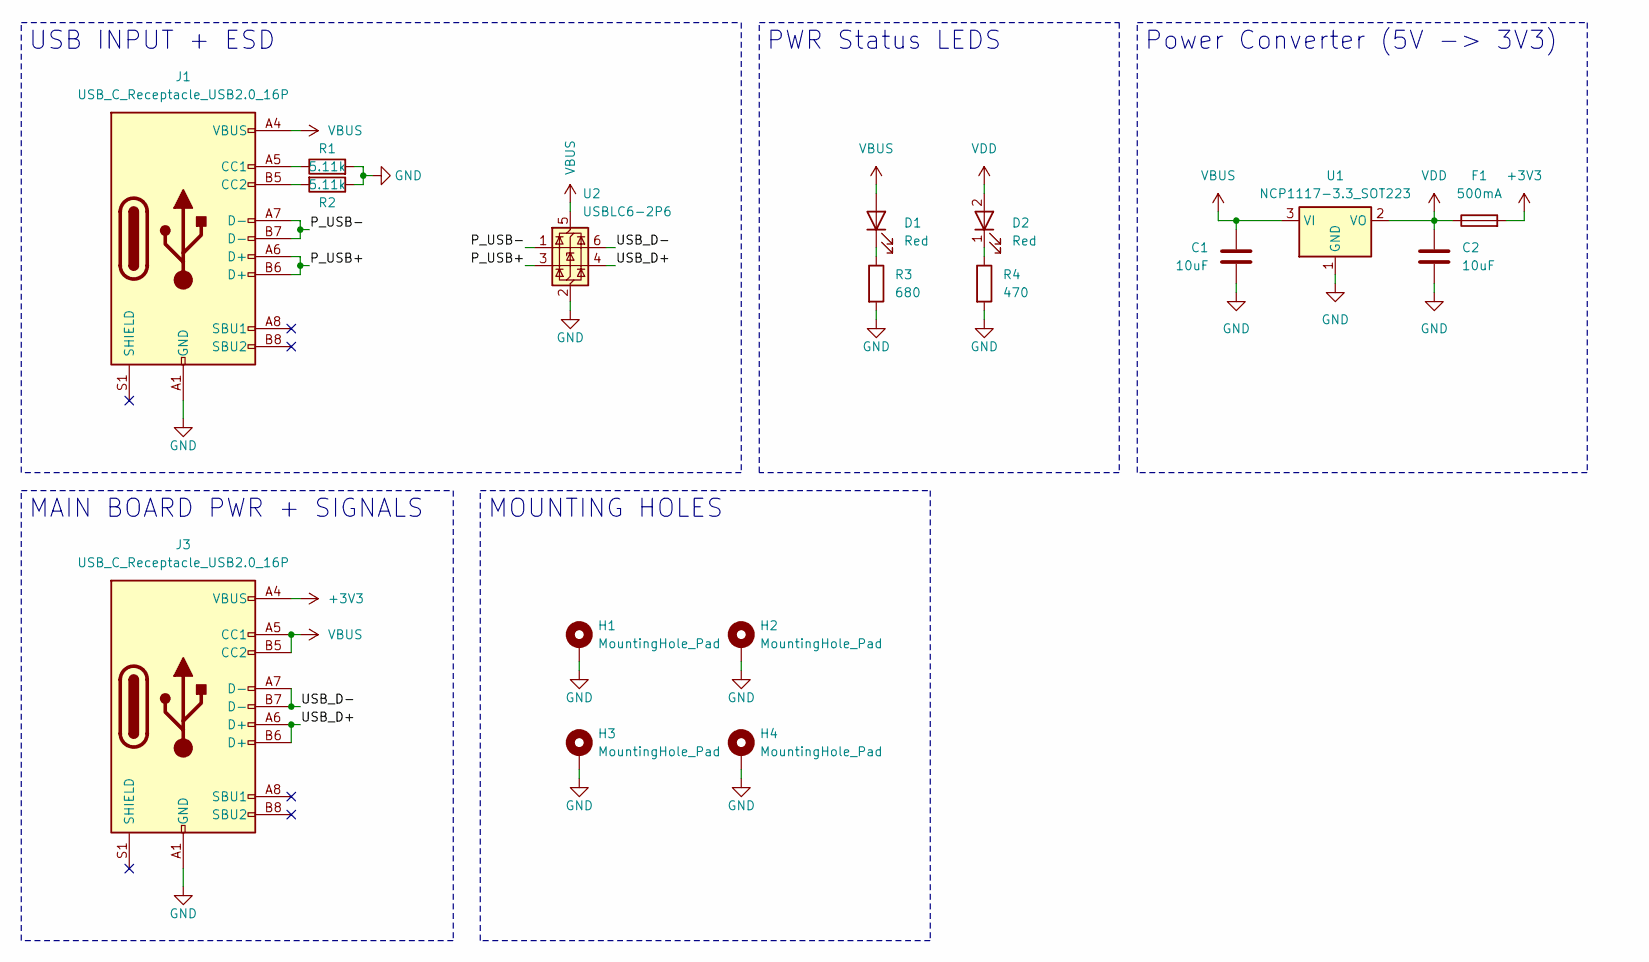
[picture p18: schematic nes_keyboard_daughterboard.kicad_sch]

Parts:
C1, C2: 10uF; C_0805_2012Metric; Part Num. CL21A106KOQNNNE
D1, D2: Red; LED_0603_1608Metric_Pad1.05x0.95mm_HandSolder; Part Num. LTST-C191KRKT
F1: 500mA; Fuse_0603_1608Metric; Part Num. ERB-RE0R50V
H1, H2, H3, H4: MountingHole_Pad; MountingHole_2.2mm_M2_DIN965_Pad
J1: USB_C_Receptacle_USB2.0_16P; USB_C_Receptacle_GCT_USB4085; Part Num. USB4085-GF-A
J3: USB_C_Receptacle_USB2.0_16P; USB_C_Receptacle_GCT_USB4105-xx-A_16P_TopMnt_Horizontal; Part Num. USB4105-GF-A
R1, R2: 5.11k; R_0603_1608Metric_Pad0.98x0.95mm_HandSolder; Part Num. RC0603FR-075K1L
R3: 680; R_0603_1608Metric_Pad0.98x0.95mm_HandSolder; Part Num. RC0603JR-07680RL
R4: 470; R_0603_1608Metric_Pad0.98x0.95mm_HandSolder; Part Num. CRGCQ0603F470R
U1: NCP1117-3.3_SOT223; SOT-223-3_TabPin2; Part Num. NCP1117LPST33T3G
U2: USBLC6-2P6; SOT-666; Part Num. USBLC6-2P6

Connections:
+3V3: F1.2, J3.A4 (VBUS), J3.A9 (VBUS), J3.B4 (VBUS), J3.B9 (VBUS)
/P_USB+: J1.A6 (D+), J1.B6 (D+), U2.3 (I/O2)
/P_USB-: J1.A7 (D-), J1.B7 (D-), U2.1 (I/O1)
/USB_D+: J3.A6 (D+), J3.B6 (D+), U2.4 (I/O2)
/USB_D-: J3.A7 (D-), J3.B7 (D-), U2.6 (I/O1)
GND: C1.2, C2.2, H1.1 (1_1), H2.1 (1_1), H3.1 (1_1), H4.1 (1_1), J1.A1 (GND), J1.A12 (GND), J1.B1 (GND), J1.B12 (GND), J3.A1 (GND), J3.A12 (GND), J3.B1 (GND), J3.B12 (GND), R1.2, R2.1, R3.2, R4.2, U1.1 (GND), U2.2 (GND)
unnamed: D1.1 (K), R3.1
unnamed: D2.1 (K), R4.1
unnamed: J1.A5 (CC1), R1.1
unnamed: J1.B5 (CC2), R2.2
VBUS: C1.1, D1.2 (A), J1.A4 (VBUS), J1.A9 (VBUS), J1.B4 (VBUS), J1.B9 (VBUS), J3.A5 (CC1), J3.B5 (CC2), U1.3 (VI), U2.5 (VBUS)
VDD: C2.1, D2.2 (A), F1.1, U1.2 (VO)

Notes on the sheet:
USB INPUT + ESD
PWR Status LEDS
MAIN BOARD PWR + SIGNALS
MOUNTING HOLES
Power Converter (5V -> 3V3)

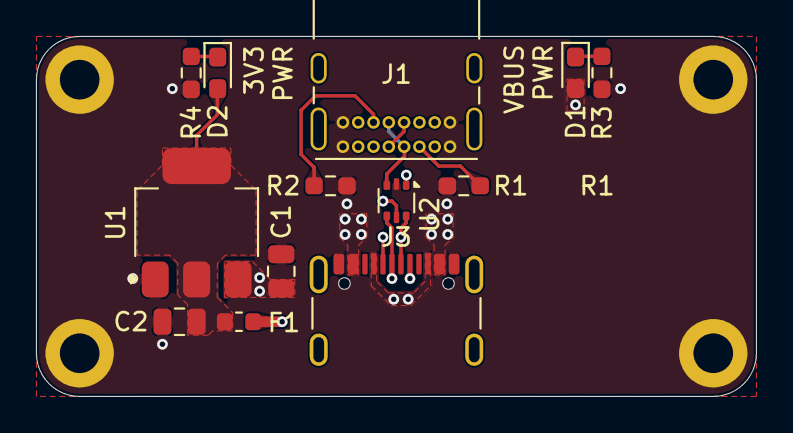
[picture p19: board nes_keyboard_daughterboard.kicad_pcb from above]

Board: 4 copper layers, 40.0 x 20.0 mm, 17 parts (0 on the bottom side), 12 nets.

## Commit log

2026-05-19 Finished V0.1
    [MCU.kicad_sch, nes_keyboard.kicad_pcb, nes_keyboard.kicad_sch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]
2026-05-27 PCB Modifications (all) - V0.2
    [daughterboard.step, nes_keyboard.kicad_pcb, nes_keyboard_daughterboard.kicad_pcb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]
2026-06-06 Updated main board + daughterboard layout - V0.3
    [MCU.kicad_sch, nes_keyboard.kicad_pcb, nes_keyboard.kicad_sch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]
2026-06-15 Added switchplate - V0.4
    [nes_keyboard.kicad_pcb, nes_switchplate.kicad_pcb, nes_switchplate.kicad_sch]
2026-06-24 Created and added 3D files - V0.5
    [Case (V2).3mf, Knob.3mf, MCU.kicad_sch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]
2026-07-15 Added Modifications to Release - V0.55
    [nes_keyboard.kicad_pcb, nes_keyboard_daughterboard.kicad_pcb]
2026-09-30 Fixed footprints, created firmware - V1
    [MCU.kicad_sch, nes_keyboard.kicad_pcb, nes_keyboard.kicad_sch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]
